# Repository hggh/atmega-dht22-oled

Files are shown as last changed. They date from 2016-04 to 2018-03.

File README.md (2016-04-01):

# atmega-dht22-oled

Platine mit Atmega328, angeschlossen an ein oLED Display und einem DHT22.

Stromversorgung über eine USB Buchse.

## Bauteile

  * 1x Atmega328
  * 1x 0,96" oLED Display
  * 1x DHT22
  * 2x 22pF Transistor
  * 1x 16MHz Quarz
  * 2x Widerstand 10k Ohm
  * 1x Widerstand 220 Ohm
  * 1x USB B Buchse (Lötmontage)

## Gehäuse

Geplant ist ein Gehäuse mit 2mm Plastikplatten.

## Gerber Plot von Kicad zu OSH Park

```
front=$(ls  *-F.Cu.gbr)
projname=$(basename $front \-F.Cu.gbr)

mv *-F.Cu.gbr $projname.GTL
mv *-B.Cu.gbr $projname.GBL
mv *-F.Mask.gbr $projname.GTS
mv *-B.Mask.gbr $projname.GBS
mv *-F.SilkS.gbr $projname.GTO
mv *-B.SilkS.gbr $projname.GBO
mv *-Edge.Cuts.gbr $projname.GKO
mv *.drl $projname.XLN
```

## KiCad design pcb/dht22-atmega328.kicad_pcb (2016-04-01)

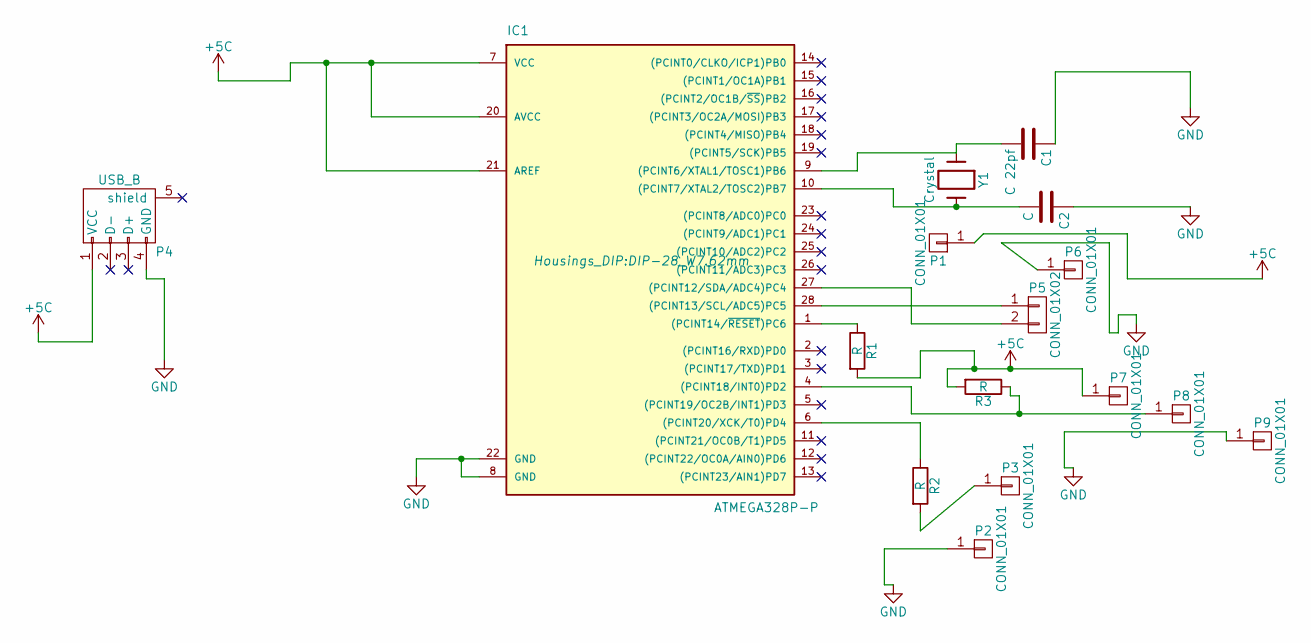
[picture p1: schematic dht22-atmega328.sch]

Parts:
C1: C 22pf; C_Rect_L7_W2_P5
C2: C; C_Rect_L7_W2_P5
IC1: ATMEGA328P-P; DIP-28_W7.62mm
P1, P2, P3, P6, P7, P8, P9: CONN_01X01; Pin_Header_Straight_1x01
P4: USB_B
P5: CONN_01X02; Pin_Header_Straight_1x02
R1, R2, R3: R; Resistor_Horizontal_RM10mm
Y1: Crystal; Crystal_HC50-U_Vertical

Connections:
+5C: IC1.7 (VCC), IC1.20 (AVCC), IC1.21 (AREF), P1.1, P4.1 (VCC), P7.1, R1.2, R3.2
GND: C1.1, C2.1, IC1.8 (GND), IC1.22 (GND), P2.1, P4.4 (GND), P6.1, P9.1
unnamed: C1.2, IC1.9 ((PCINT6/XTAL1/TOSC1)PB6), Y1.1
unnamed: C2.2, IC1.10 ((PCINT7/XTAL2/TOSC2)PB7), Y1.2
unnamed: IC1.1 ((PCINT14/~RESET~)PC6), R1.1
unnamed: IC1.4 ((PCINT18/INT0)PD2), P8.1, R3.1
unnamed: IC1.6 ((PCINT20/XCK/T0)PD4), R2.1
unnamed: IC1.27 ((PCINT12/SDA/ADC4)PC4), P5.2
unnamed: IC1.28 ((PCINT13/SCL/ADC5)PC5), P5.1
unnamed: P3.1, R2.2

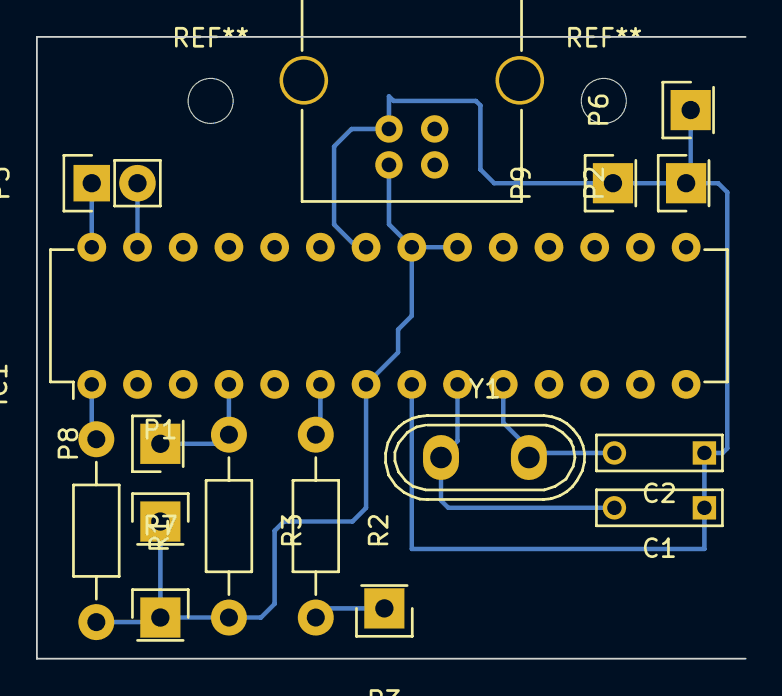
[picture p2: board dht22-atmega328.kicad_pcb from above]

Board: 2 copper layers, 39.4 x 34.5 mm, 16 parts (0 on the bottom side), 10 nets.

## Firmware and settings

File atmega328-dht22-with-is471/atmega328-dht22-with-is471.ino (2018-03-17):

#include <avr/wdt.h>
#include <SPI.h>
#include <Wire.h>
#include <DHT.h>
#include <Adafruit_GFX.h>
#include <Adafruit_SSD1306.h>


#define OLED_RESET 4
Adafruit_SSD1306 display(OLED_RESET);

#define SENSOR_PIN 2
#define DHTTYPE DHT22
#define IS471_PIN 3
#define DISPLAY_POWER_PIN A3


DHT dht(SENSOR_PIN, DHTTYPE);
float temperature = 99.0;
float humidity = 99.0;
volatile unsigned short timer_runs;
volatile unsigned short timer_status;

ISR(TIMER1_OVF_vect) {
  TCNT1 = 0;
  timer_runs++;

  if (timer_runs > 5) {
    timer_status = 100;

    cli();
    TCCR1A = 0;
    TCCR1B = 0;
    sei();
  }
}

void is471_interrupt() {
  cli();
  TCCR1A = 0;
  TCCR1B = 0;
  TCNT1  = 0;

  TCCR1B |= (1 << CS12) | (1 << CS10);
  TIMSK1 |= (1 << TOIE1);
  sei();
  timer_runs = 0;
  timer_status = 1;
}


void setup() {
  pinMode(DISPLAY_POWER_PIN, OUTPUT);
  digitalWrite(DISPLAY_POWER_PIN, LOW);

  pinMode(IS471_PIN, INPUT);
  attachInterrupt(digitalPinToInterrupt(IS471_PIN), is471_interrupt, FALLING);
  
  dht.begin();
  timer_status = 0;
}


void display_values(float h, float t) {
  String humidity_s = String(int(h));
  String temperature_s = String(int(t));
  
  display.clearDisplay();
  display.setTextColor(WHITE);
  
  display.setTextSize(1);

  display.setCursor(10, 0);
  display.print("C");
  display.setCursor(15, 0);
  display.drawCircle(20, 2, 1, WHITE);
  display.setCursor(95, 0);
  display.print("rh %");

  // line between description and values
  display.drawLine(0,7,128,7, WHITE);


  display.setTextSize(3);
  display.setCursor(0,10);
  display.print(temperature_s);

  display.drawCircle(temperature_s.length() * 19, 14, 3, WHITE);
  display.setTextSize(2.5);
  display.setCursor(temperature_s.length() * 19, 17);
  display.print('c');


  display.setTextSize(2.5);
  display.setCursor(89, 15);
  display.print(humidity_s);
  display.setTextSize(1);
  display.setCursor(89 + humidity_s.length() * 15, 22);
  display.print('%');

  display.display();
}

void loop() {
  temperature = dht.readTemperature();
  humidity = dht.readHumidity();

  if (isnan(temperature) || isnan(humidity)) {
    return;
  }

  if (timer_status == 1) {
    digitalWrite(DISPLAY_POWER_PIN, HIGH);
    display.begin(SSD1306_SWITCHCAPVCC, 0x3C);
    display_values(humidity, temperature);

    timer_status = 10;
  }
  if (timer_status == 10) {
    display_values(humidity, temperature);
  }
  if (timer_status == 100) {
    display.clearDisplay();
    display.display();
    digitalWrite(DISPLAY_POWER_PIN, LOW);

    timer_status = 0;
  }

  delay(1000); 
}

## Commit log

2016-04-01 added lcb
    [dht22-atmega328.kicad_pcb, dht22-atmega328.sch]
2016-04-01 fix pcb
    [dht22-atmega328.kicad_pcb]
2018-03-17 added with is471 sensor
